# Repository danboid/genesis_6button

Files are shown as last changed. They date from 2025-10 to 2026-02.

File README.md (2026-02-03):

# Six button Sega Mega Drive / Genesis controller board

This repository contains a KiCad project for a six button Sega Mega Drive / Genesis controller board as well as ATTiny404 micro controller code to implement a replacement for the 6 button Sega Mega Drive controller's custom chip. This board is also compatible with the ZX Spectrum Next and its clones.

**Note: the `main` HEAD is not necessarily tested! Tested revisions of the board+firmware will be tagged**

## How do I program the controller?

**DISCLAIMER: This project is provided "as is" for educational purposes only. The authors shall not be held liable for any damage to equipment, data loss, or personal injury incurred through the assembly or use of this project. Proceed at your own risk.**

The ATtiny404 uses UPDI (Unified Program and Debug Interface) for programming, not ISP like older AVR MCUs. 

There are several ways to program the ATtiny404 but probably the most affordable way is to use **avrdude** with a USB serial adapter. serialupdi mode has been supported by **avrdude** since v7.

You will need the following:

* A USB serial adapter such as the [FTDI FT232](https://www.amazon.co.uk/dp/B07BBPX8B8)
* A 4.7 KOhm resistor. A resistor in the range of 3.3K to 10KOhm should be fine if you don't have a 4.7KOhm resistor.
* 5x female to female jumper (DuPont) wires.

The +5V and GND headers are wired directly from the serial adapter to the UPDI header. You must create a "Y" jumper cable that connects both the RX and TX pins on your serial adapter to the single UPDI pin on the controller PCB.

The UPDI pin is the bottom left UPDI header pin that has the square footprint in this schematic screenshot. The resistor needs to be connected to the TX wire of your Y cable. Ensure that your serial adapter voltage selection header is set to 5V.

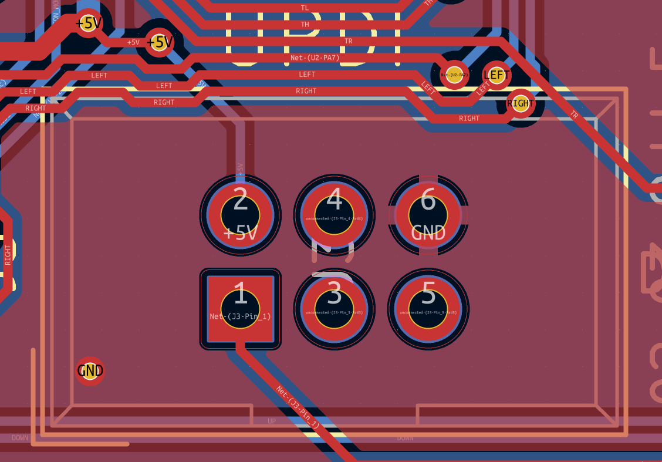
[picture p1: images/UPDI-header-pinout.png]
UPDI header schematic


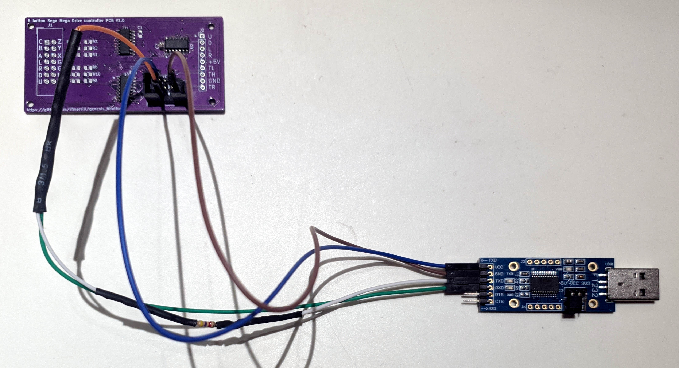
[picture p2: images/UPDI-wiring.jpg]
USB serial to UPDI header wiring


You should only need to have the ATtiny and the UPDI header soldered to the PCB to program it.

Once you have the board connected as shown above, you can program the firmware under Linux using:

```
avrdude  -p t404 -c serialupdi -P /dev/ttyUSB0 -U flash:w:main.hex
```

Or under Windows:

```
avrdude.exe -p t404 -c serialupdi -P COM6 -U flash:w:main.hex
```

Make sure you set the serial port device correctly by checking **dmesg** output under Linux or **Device Manager** under Windows.

## Building a joystick

The cable is connected to the J2 header using this pinout:

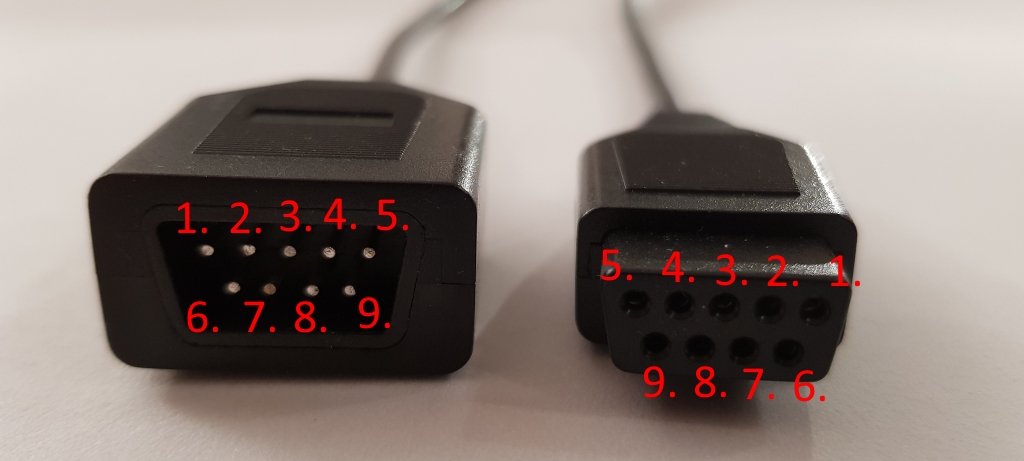
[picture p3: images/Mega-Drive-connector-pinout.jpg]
Mega Drive controller cable pinout


Pin 1 on J2 and all of the chips is marked on the PCB silkscreen with a small white dot to the side of pin 1.

Here's photo of this board wired up to a Sanwa clone joystick and housed within a 3D printed [Uzebox fightstick](https://uzebox.org/wiki/Joystick) case:

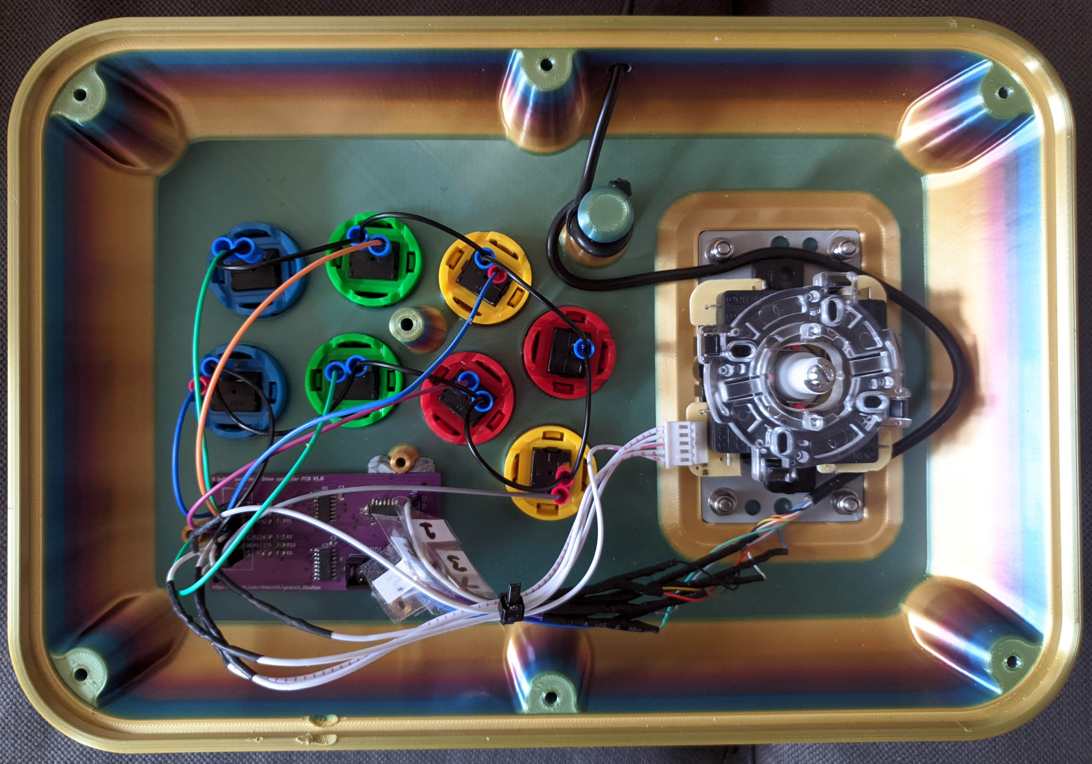
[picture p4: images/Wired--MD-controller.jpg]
Sanwa joystick in Uzebox fightstick case


## Credits

Schematic and ATtiny code by [R.F.Merrill](https://github.com/rfmerrill)

Silkscreen and documentation by [Dan MacDonald](https://github.com/danboid/)

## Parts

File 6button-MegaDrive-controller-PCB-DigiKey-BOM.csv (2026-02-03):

Digi-Key Part Number | Quantity | Reference | Value | Manufacturer | Manufacturer Product Number | Description | Datasheet
478-KGM21NR71H104KTCT-ND | 10 | C1,C2,C3 | 0.1u | KYOCERA AVX | KGM21NR71H104KT | CAP CER 0.1UF 50V X7R 0805 – Only 3 needed but cheaper to buy 10 than 3 | ~
A122908-ND | 1 | J1 | CONN HEADER VERT 14POS 2.54MM | TE Connectivity AMP Connectors | 826632-7 | Connector Header Through Hole 14 position 0.100" (2.54mm) | ~
2057-PH1-09-UA-ND | 1 | J2 | CONN HEADER VERT 9POS 2.54MM | Adam Tech | PH1-09-UA | Connector Header Through Hole 9 position 0.100" (2.54mm) | ~
2057-BHR-06-VUA-ND | 1 | J3 | CONN HEADER VERT 6POS 2.54MM | Adam Tech | BHR-06-VUA | Connector Header Through Hole 6 position 0.100" (2.54mm) | ~
A102341CT-ND | 12 | R1,R2,R3,R4,R5,R6,R7,R8,R9,R10,R11,R12 | 75k | TE Connectivity Passive Product | CPF0805B75KE1 | 75 kOhms ±0.1% 0.1W, 1/10W Chip Resistor 0805 (2012 Metric) Thin Film | ~
296-CD74HC257M96CT-ND | 2 | U1,U3 | 74HC257 | Texas Instruments | CD74HC257M96 | Multiplexer 4 x 2:1 16-SOIC | http://www.ti.com/lit/gpn/sn74LS257
ATTINY404-SSNRCT-ND | 1 | U2 | ATTINY404-SSNR | Microchip Technology | ATTINY404-SSNR | AVR tinyAVR™ 0, Functional Safety (FuSa) Microcontroller IC 8-Bit 20MHz 4KB (4K x 8) FLASH 14-SOIC | http://ww1.microchip.com/downloads/en/DeviceDoc/50002687A.pdf

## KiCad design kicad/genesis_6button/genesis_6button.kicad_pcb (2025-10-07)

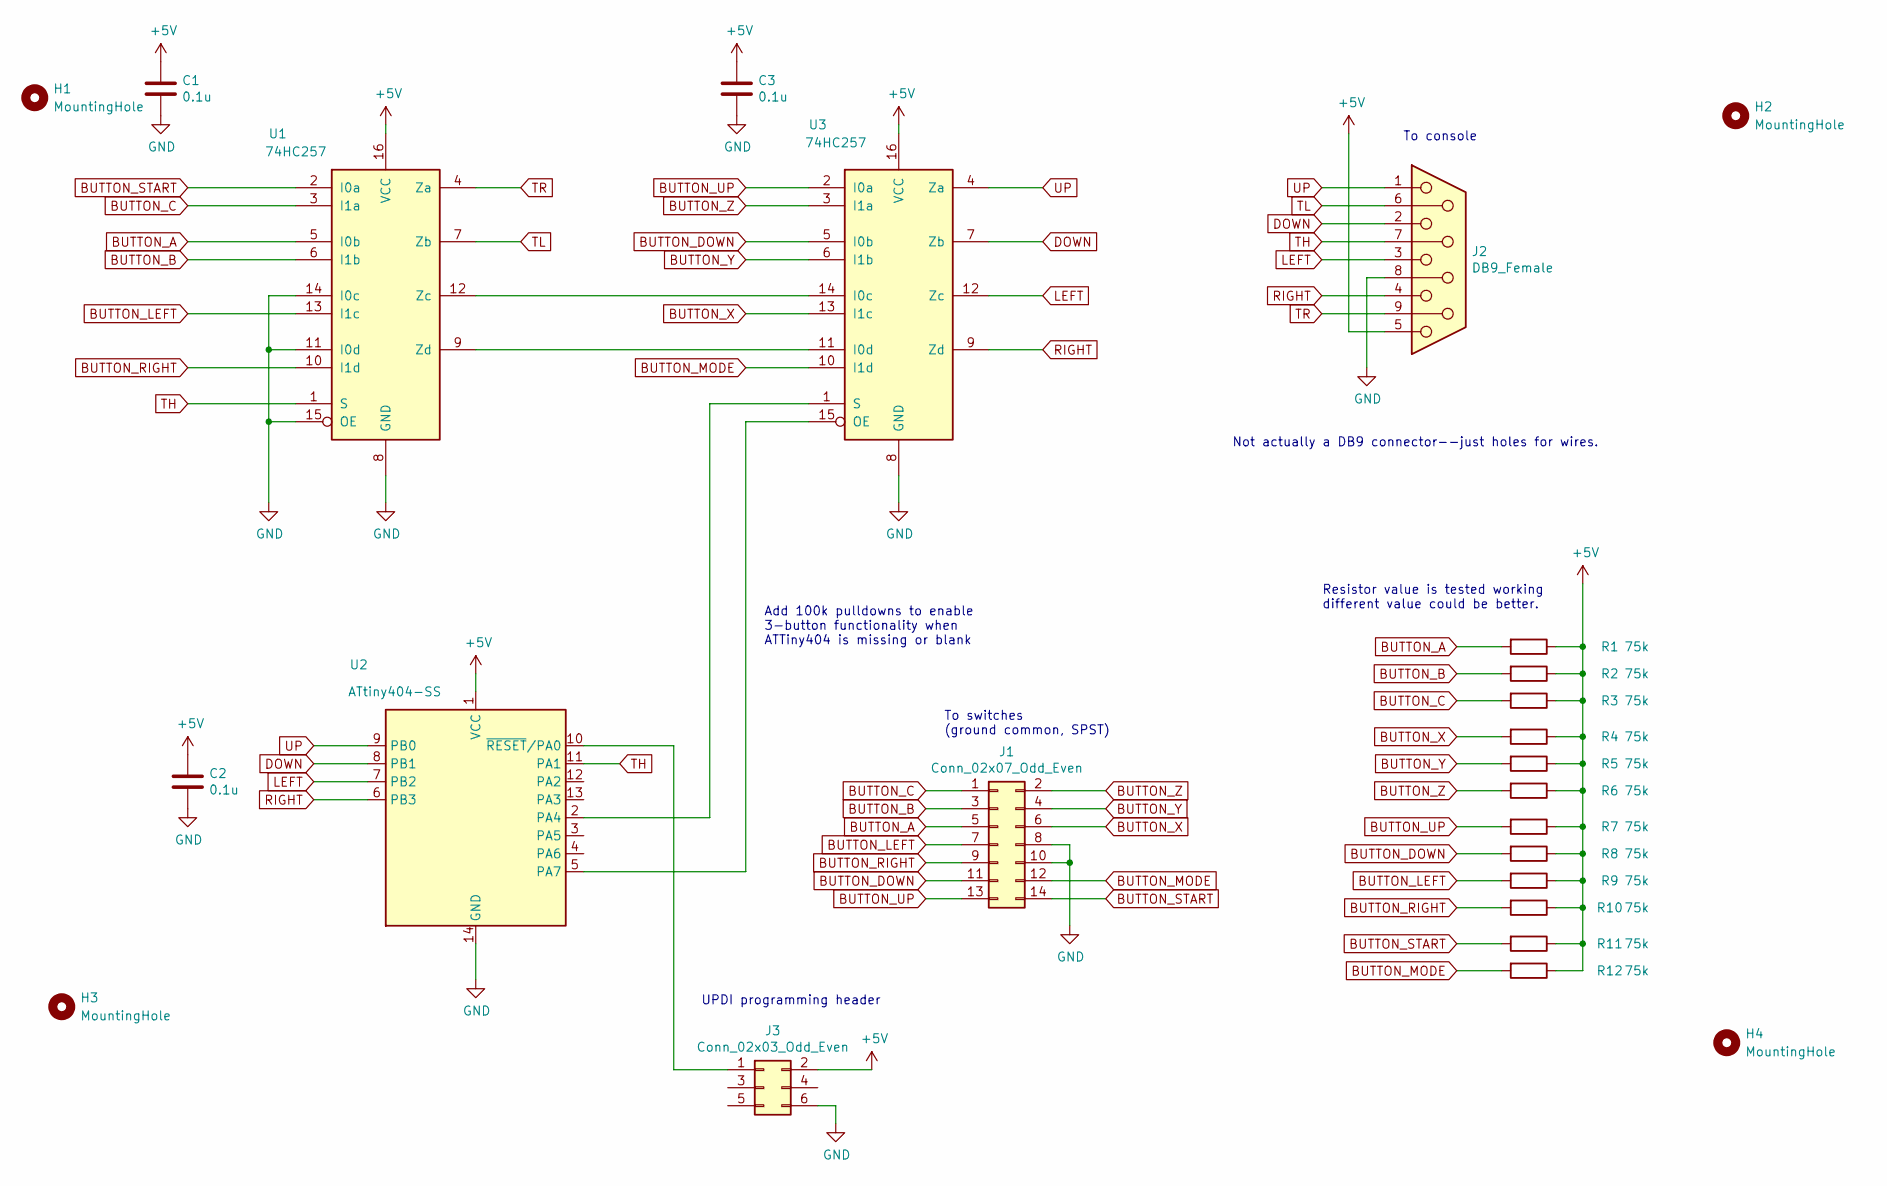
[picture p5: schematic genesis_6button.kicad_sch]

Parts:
C1, C2, C3: 0.1u; C_0805_2012Metric
H1, H2, H3, H4: MountingHole; MountingHole_2.2mm_M2
J1: Conn_02x07_Odd_Even; IDC-Header_2x07_P2.54mm_Vertical
J2: DB9_Female; PinHeader_1x09_P2.54mm_Vertical
J3: Conn_02x03_Odd_Even; IDC-Header_2x03_P2.54mm_Vertical
R1, R2, R3, R4, R5, R6, R7, R8, R9, R10, R11, R12: 75k; R_0805_2012Metric
U1, U3: 74HC257; SOIC-16_3.9x9.9mm_P1.27mm
U2: ATtiny404-SS; SOIC-14_3.9x8.7mm_P1.27mm

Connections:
+5V: C1.1, C2.1, C3.1, J2.5, J3.2, R1.1, R2.1, R3.1, R4.1, R5.1, R6.1, R7.1, R8.1, R9.1, R10.1, R11.1, R12.1, U1.16 (VCC), U2.1 (VCC), U3.16 (VCC)
BUTTON_A: J1.5, R1.2, U1.5 (I0b)
BUTTON_B: J1.3, R2.2, U1.6 (I1b)
BUTTON_C: J1.1, R3.2, U1.3 (I1a)
BUTTON_DOWN: J1.11, R8.2, U3.5 (I0b)
BUTTON_LEFT: J1.7, R9.2, U1.13 (I1c)
BUTTON_MODE: J1.12, R12.2, U3.10 (I1d)
BUTTON_RIGHT: J1.9, R10.2, U1.10 (I1d)
BUTTON_START: J1.14, R11.2, U1.2 (I0a)
BUTTON_UP: J1.13, R7.2, U3.2 (I0a)
BUTTON_X: J1.6, R4.2, U3.13 (I1c)
BUTTON_Y: J1.4, R5.2, U3.6 (I1b)
BUTTON_Z: J1.2, R6.2, U3.3 (I1a)
DOWN: J2.2, U2.8 (PB1), U3.7 (Zb)
GND: C1.2, C2.2, C3.2, J1.8, J1.10, J2.8, J3.6, U1.8 (GND), U1.11 (I0d), U1.14 (I0c), U1.15 (OE), U2.14 (GND), U3.8 (GND)
LEFT: J2.3, U2.7 (PB2), U3.12 (Zc)
unnamed: J3.1, U2.10 (~RESET/PA0)
unnamed: U1.12 (Zc), U3.14 (I0c)
unnamed: U1.9 (Zd), U3.11 (I0d)
unnamed: U2.2 (PA4), U3.1 (S)
unnamed: U2.5 (PA7), U3.15 (OE)
RIGHT: J2.4, U2.6 (PB3), U3.9 (Zd)
TH: J2.7, U1.1 (S), U2.11 (PA1)
TL: J2.6, U1.7 (Zb)
TR: J2.9, U1.4 (Za)
UP: J2.1, U2.9 (PB0), U3.4 (Za)

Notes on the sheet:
UPDI programming header
Add 100k pulldowns to enable 3-button functionality when ATTiny404 is missing or blank
To console
Not actually a DB9 connector--just holes for wires.
To switches (ground common, SPST)
Resistor value is tested working different value could be better.

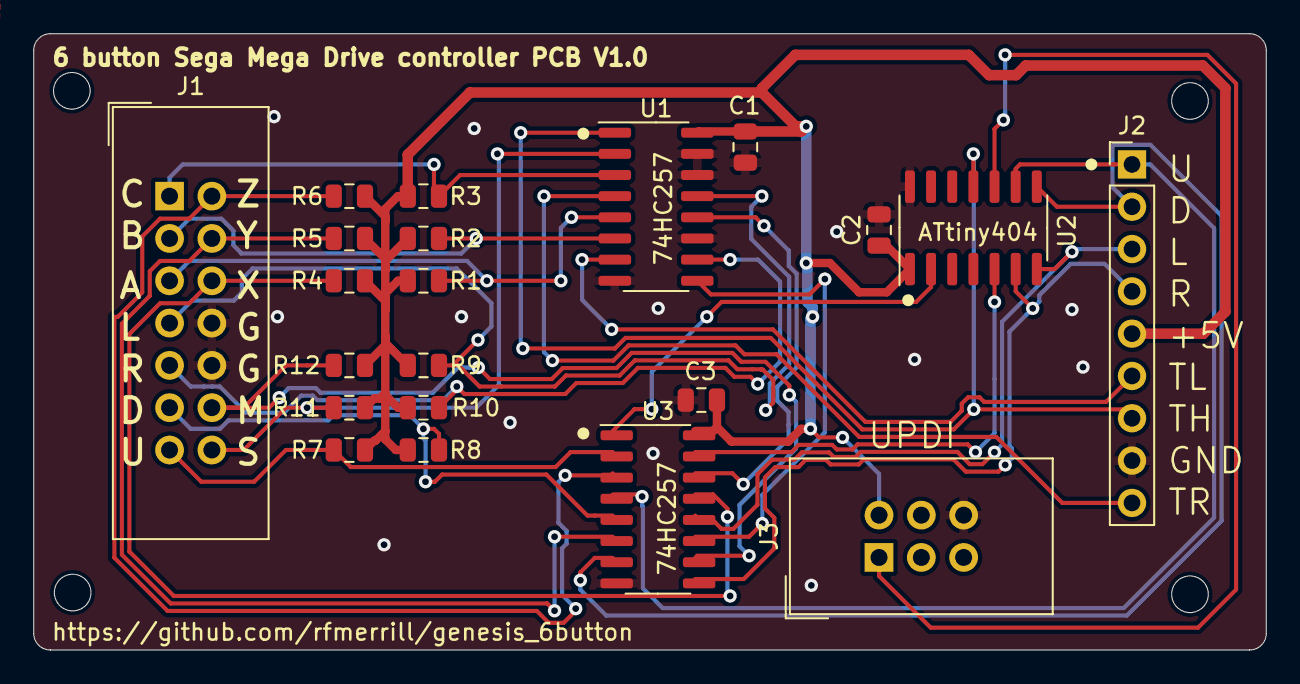
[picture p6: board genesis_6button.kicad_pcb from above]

Board: 2 copper layers, 74.0 x 37.0 mm, 25 parts (0 on the bottom side), 26 nets.

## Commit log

2025-10-04 Revert to first revision of PCB
    [genesis_6button.kicad_pcb, genesis_6button.sch]
2025-10-04 Move U3 slightly to fix a thermal relief error
    [genesis_6button.kicad_pcb]
2025-10-04 Add extra labels to front silkscreen
    [genesis_6button.kicad_pcb]
2025-10-04 Add version number to front silkscreen
    [genesis_6button.kicad_pcb]
2025-10-04 Add M2 mount holes
    [genesis_6button.kicad_pcb, genesis_6button.kicad_sch]
2025-10-04 Add buttons to silkscreen
    [genesis_6button.kicad_pcb]
2025-10-04 Round off PCB corners
    [genesis_6button.kicad_pcb]
2025-10-06 Add programming and wiring instructions to README
2025-10-07 Second revision of silkscreen
    [genesis_6button.kicad_pcb]
2025-10-07 Add gerbers zip file for v1.0
    [genesis_6button.kicad_pcb]
2025-10-09 Add DigiKey BOM
    [6button-MegaDrive-controller-PCB-DigiKey-BOM.xlsx]
2025-11-11 Add Arduino project files
2025-11-30 Add tested avrdude instructions and UPDI wiring images
2025-11-30 Add instructions for finding correct serial device
2025-11-30 Add note about required PCB components for programming the ATtiny
2025-12-03 Remove link to old OSHpark board
2025-12-03 Rename MD connector pinout image
2025-12-03 Add csv BOM
    [6button-MegaDrive-controller-PCB-DigiKey-BOM.csv]
2025-12-27 Update README with a photo of a wired joystick and buttons
2026-02-03 Remove duplicate connector image
2026-02-03 Add Manufacturer and Manufacturer Product Number columns to BOM files
    [6button-MegaDrive-controller-PCB-DigiKey-BOM.csv, 6button-MegaDrive-controller-PCB-DigiKey-BOM.xlsx]
